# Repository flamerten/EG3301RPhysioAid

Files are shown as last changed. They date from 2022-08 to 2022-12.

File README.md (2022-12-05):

# Development of a Physiotherpay Aid
A project done by EIM322 with the National University of Singapore's Innovation and Design Programme([iDP](https://cde.nus.edu.sg/idp/academics/overview/)). Under the Innovating for a Better Healthcare Track, we propose the use of multiple knee wearables during group physiotherapy sessions, allowing physiotherapists to identify patients that are struggling and devote more time into correcting their form or modifying their individual exercises.

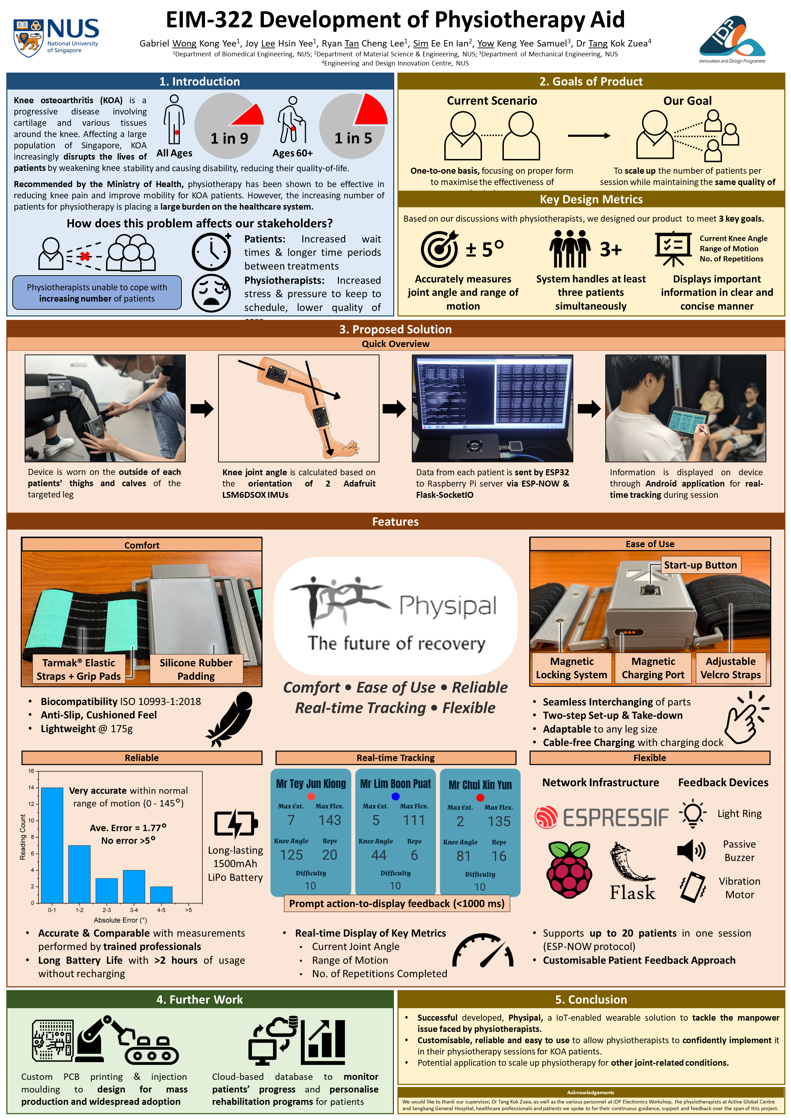
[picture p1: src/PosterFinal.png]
Poster


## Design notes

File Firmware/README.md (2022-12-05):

# Firmware

This is the set of files where we use the Adafruit components to reduce the size, the M5 was quite thick and didn't have some features that we wanted so we changed our electronic components.

# Hardware

## List of key components
- [ESP32 Feather V2](https://www.adafruit.com/product/5400)
- [LSM6DSOX 6 DoF Accelerometer and Gyroscope](https://www.adafruit.com/product/4438)
- [LC709203F LiPoly / LiIon Fuel Gauge and Battery Monitor](https://www.adafruit.com/product/4712)
- [Tactile Switch Buttons(12x12x6)](https://www.adafruit.com/product/1119)
- [Pogo Pin Connectors](https://shopee.sg/5-Pairs-Spring-Loaded-Magnetic-Pogo-Pin-Connector-3-Positions-Magnets-Pitch-2.3MM-Through-Holes-Male-Female-Probe-i.174316421.13592238478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)
- [Vibration Motor Module](https://shopee.sg/PWM-Vibration-Motor-Module-DC-Motor-Mobile-Phone-Vibration-Vibrator-Mini-Switch-Sensor-Module-DIY-for-Arduino-DC-5V-i.56539845.10481910192)
- [1500mah Lipo Battery](https://www.continental.sg/3-7v-rechargeable-1500mah-li-po-battery.html) - Continental Electronics, Sim Lim Square
- [5V Boost Converter](https://shopee.sg/5pcs-lot-0.9-5V-To-5V-DC-DC-Step-Up-Power-Module-Voltage-Boost-Converter-Board-1.5V-1.8V-2.5V-3V-3.3V-3.7V-4.2V-To-5V-i.56539845.12267989957)

## Adafruit
Note that we chose Adafruit because their components are of pretty solid quality and their STEMMA QT Cables are pretty useful for the i2c wiring. We also used that ESP32 feather because it came with battery charging capabilities. 

The pogo pin connectors were used for charging and for connecting the upper casing to the lowercasing. The lower casing houses the Vibration Motor as it needs to be close to the skin.

The tactile switch buttons we used are slightly bigger than the typical ones, and are generally alot easier to press. 

Note that the LiPo batteries must be bought locally, as they take very long to be shipped over. They also must be treated carefully and cannot be pierced by screws/sharp parts or overcharged. The Feather handles this well.

The Motor is connected to a Boost Converter to as it will increase the voltage across the motor and hence the magnitude of vibration

## Electrical Circuits

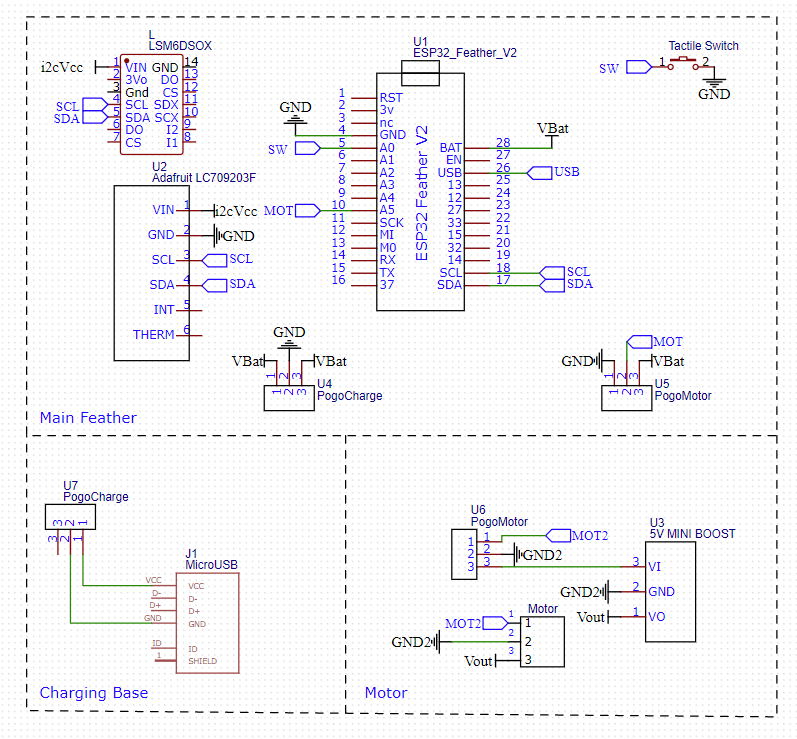
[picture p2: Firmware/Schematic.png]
Electrical Circuit


Note that the LIPO Battery should be connected to the LC709203F via JST, then the other JST cable from the LCF70920 will run to VBat in the Huzzah and the the Ground wire connects to GND.

# Software

The communication relied on [ESP-NOW](https://randomnerdtutorials.com/esp-now-esp32-arduino-ide/), with the MAC ADDRESSES specified in the codes. The Feather with the motor is denoted as the **Slave** while the one without is denoted as the  **Master**. The Slave calculated the orientation and transmits it to the Master. The Master then calculated the joint angle in this format, with maximum flexion being 0 degrees. This was advised by Mark from Active Global

    joint_angle = 180 - abs(180 - int(abs(slave_angle - roll)));

The Master then uses ESP-NOW to transmit data to the M5. The M5 then processes the joint angle from multiple Feathers and transmits it to the Raspberry Pi via Serial to be processed. When the Raspberry Pi senses that a patient has completed a repetition by hitting the max/min, it sends the patient number via Serial to the M5. The M5 then sends an ESP-NOW message to the Slave, which will vibrate the motor. 

The orientation is calculated via the AHRS algorithm provided by [MadgwickAHRS Library](https://github.com/arduino-libraries/MadgwickAHRS). As the Magdwick Algorithm relies on gradient descent, we found that the first few seconds of data were generally inaccurate as it was still descending to the actual position. As such, the first 10s of readings were ignored, and data only starts to be transmitted after that.

The Magdwick Algorithm calculated roll and pitch. However, we needed Yaw, as this was the optimal placement of the LSM in the wearable. As such, the frame was rotated and fed into the Magdwick Algorithm, such that the roll calculated is actually the Yaw.

    //filter.updateIMU(gx, gy, gz, ax, ay, az);  //Original
    filter.updateIMU(gz, gy, -1.0*gx, az, ay, -1.0*ax); //Yaw, rotated > used

I also noted that the readings were incredibly noisy when the LSM faced upwards, with its Z axis pointing up. I believe its because only one axis is used. Once it is tilted, it is able to utilise readings from multiple axis. Refer to (this)[https://community.nxp.com/t5/Sensors/6DOF-GY-KALMAN-Yaw-drift/m-p/457552] forum post i found.

## Notes
Note that PATIENT_NO = 0 is old prototype with the IMU rotated and holes in the board  Hence, the Battery indicator brightness is lower and the orientation calculation is different. These are accounted for in the code with if else statements

# Mac Addresses

M5
- {0x4C,0x75,0x25,0xC4,0xFA,0xF4}; 

Patient 1 (NEW) -> purely grey
- New Master: {0xE8,0x9F,0x6D,0x26,0x09,0x20}
- New Slave: {0xE8,0x9F,0x6D,0x1F,0xFD,0xB8}

Patient: 0 (OLD PROTO) -> Large prototypes
- Old Master: {0xE8,0x9F,0x6D,0x25,0x3C,0x24}
- Old Slave:  {0xE8,0x9F,0x6D,0x28,0x0C,0x98}

Patient 2 (Newest Feathers) - Turqoise Casing
- Master: {0xE8,0x9F,0x6D,0x25,0x47,0x08}
- Slave:{0xE8:0x9F,0x6D,0x25,0x46,0x70}

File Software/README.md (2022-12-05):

# Software

A Raspberry Pi running Flask SocketIO was used to set up the network for the wearable to communicate with the mobile phone. The mobile phone application for physiotherapists was developed using Android Studio.

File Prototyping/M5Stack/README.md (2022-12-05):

# M5Stack - Initial Prototyping

This folder contains the master and slave codes, for 2 slave M5s to connect to 1 M5. This M5 is connected to my computer and outputs the rolls of each M5 and the joint angle. The angle is calculated by this way, with rolls_rsv containing the rolls of the 2 IMUs.

    angle_knee = int(abs(rolls_rcv[0] - rolls_rcv[1]) );
    if(angle_knee > 180) angle_knee = 360 - angle_knee;

The communication relied on [ESP-NOW](https://randomnerdtutorials.com/esp-now-esp32-arduino-ide/). The roll is calculated by the AHRS algorithm provided by [M5 docs](https://docs.m5stack.com/en/api/atom/mpu).

When the slave M5s have turned on, they start a calibration sequence. As it is gradient descent, i give the condition that i need to do calibration for at least 3s, and that the difference between the max and min must be less that 1 degrees. This ensures that the reading has stablised. This offset is added to the future rolls added.

Once the calibration has been done, the slave M5s send a message every 1s via esp-now to the master device, in order to start the syncing. This allows the M5s to send the angles at the same period and similiar timings. Similar because if its exactly the same there might be some conflict when ESP-NOW sends its messages. So i add a small delay of 50ms.

This broadcast/callibration message consists of the slave MacAddress. It only starts sampling when it has recieved the order from the master M5 to start sampling. The reason for the MacAddress is that this allows the M5 master to differentiate M5s. Also, the message to start sampling is sent to both slave M5s, once 2 **different** esp now messages with different Mac addresses are recieved. The sending is sent to the slave M5s, with the message containing sampling rate and also a different roll angle to another device. 

From there both M5s sample the roll and send it via ESP-NOW to the master M5. The sampling rate is decided by the Master. 

The isssue is that the plan needs to be parallel to the z axis, meaning that the top of the M5 must point to the sky vertically.

#
## Updates
### 31/08/2022
Testing was generally good, the issue of calibration still not solved. However, the angles are relatively accurate when the devices are put on properly. An indicator is used to show which M5 recieves which message. I noticed there were some times where one M5 stop transmitting. The Master M5 indicator only showed one M5 sending, so not too sure why, will test and see the reason.

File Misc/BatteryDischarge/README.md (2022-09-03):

# Power Source

This folder details experiments and changes made to the power supply of the physiotherapist wearable.  This is neccessary to ensure physiotherapists charge the device to ensure it does not run out of charge, and to fully utilise the capacity of the battery.

## 03/09/22
#

## **Resistors**

The aim of the experiment was to see if using potential difference was a feasible way of estimating battery capacity. A multimeter was used to get the true value of the potential difference and that value is compared to the analogRead when resistors are applied in a potential divicer circuit. This is the circuit used:

    VCC - R1 * R1 - GND 
    
with * being where the analogRead is taken from. The reason for this is because our MCU is 3.3V logic level. As the battery has a maximum voltage level of 4.2V, this is to ensure the logic level is not exceeded.

From some preliminary experiements, there was quite abit of inaccuracy. Firstly, with higher resistances, the ADC within the MCU is more inaccurate as it works by storing charge. Hence, the low current decreases accuracy.

However at lower resistances, alot of voltage is lost to power loss due to the current at the branch. As such there was a consistent offset.

| Resistance  | Multimeter Voltage | Actual Volage |
| --- | --- | --- |
| 270 &Omega; | 2.59V | 2.74V | 
| 1 M&Omega;  | 2.45V | 2.08V - 2.74V |
| 100 K&Omega;| 2.58V | 2.40V |

As noticed the resistance did not seem to affect the offset heavily. However, a higher resistance had a very sigificant amount of fluctuation

## **Voltage Discharge**

A DC Motor Was used to discharge a fully charged LION battery and its potential difference was measured using 100K&Omega; resistors. The potential difference was sampled every 1s using the M5 Atom's ADC pin, and recorded on to a CSV file.

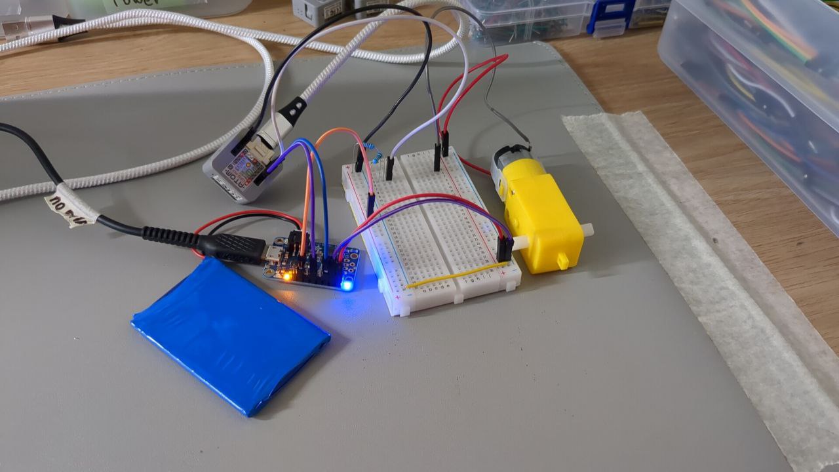
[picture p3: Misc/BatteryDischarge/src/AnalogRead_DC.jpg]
Electrical Setup


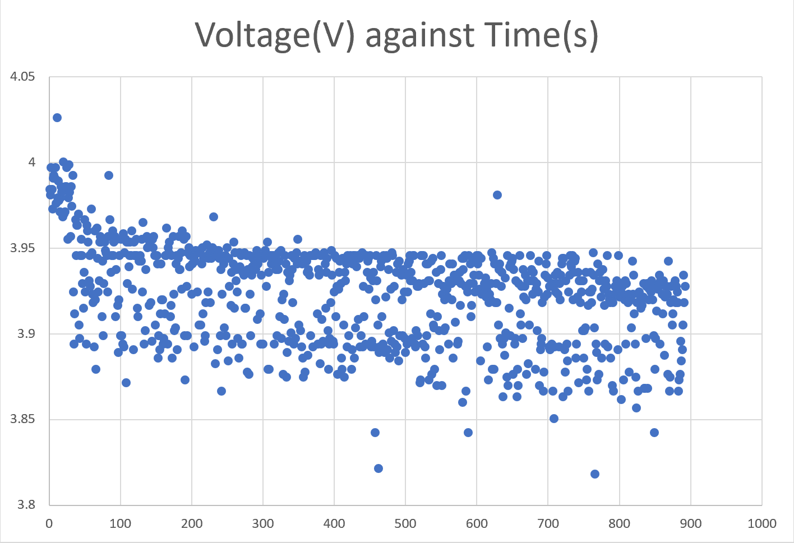
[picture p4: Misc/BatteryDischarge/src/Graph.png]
Voltage Graph Graph of Voltage Against Time


The voltage graph had alot of fluctuation. Although granted that this could be due to signal noise, but it might mean that we might need to implement some signal filtering techniques when using this method to estimate battery capacity. However, from this graph, it does not look like a very reliable method and we might need to consider using other methods to get the capacity of the battery.

Some possible Alternative Ways coule be using breakout boards that monitor the capacity of the battery.

## *Possible Links*

[Single Li-Ion and LiPoly Battery Power Meter](https://www.adafruit.com/product/5383)

[Adafruit LC709203F LiPoly / LiIon Fuel Gauge and Battery Monitor](https://www.adafruit.com/product/4712)

[Adafruit MAX17048 LiPoly / LiIon Fuel Gauge and Battery Monitor](https://www.adafruit.com/product/5580)

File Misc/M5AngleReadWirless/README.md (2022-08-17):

# M5AngleReadWireless

This folder contains the a master and slave code where a M5 Atom Matrix with the inbuilt MPU6886 to read the 6 axis IMU readings. These readings are processed through the AHRS algorithm provided by M5 docs and then sent via ESP-NOW to a master M5. The master M5 reads this data and prints them onto a serial monitor.

Note for use with another MCU, you need to change the mac address

The current mac address that recieves the angles is: {0x4C,0x75,0x25,0xC4,0xFA,0xF4}

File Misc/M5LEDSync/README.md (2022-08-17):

# M5 LED Sync

Initial testing code for syncing LEDS, using ESP-now

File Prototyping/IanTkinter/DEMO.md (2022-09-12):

# Demo Instructions

## Requirements
    matplotlib==3.5.2
    pyserial==3.5

This files details the steps for using the M5 IMUs with guibuild file, to show the joint angle in real time. This demo is the same as how we demoed with Mark at Active Global.

1) Using a type c cable, plug the Master M5 Atom into the USB port of a computer. Check that the cable is a data cable, by opening `Device Manager > Ports ` If you see the M5 atom there then you are good to go. Note that the Master M5 Atom has a grey wire on it, while the slaves do not have any wires at the GPIO ports

2) Attach 2 `Tailbat`s to the slave atoms. It should turn on immediately and show the green battery bar. If not press once. If there is no red light, the `Tailbat` has run out of battery, use another one. 

3) Note that there is no more callibration. After 2s, the master M5 should have 2 flashing RGB lights. This signifies that it is recieving data from the 2 slave atoms

4) Run the guibuild.py file. A Window should show the real time data of joint angle between the 2 M5 IMUs.

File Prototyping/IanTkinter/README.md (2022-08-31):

# Ian Tkinter

This folder shows Ian's work on using Tkinter to display data coming from the M5 with the connection through serial port

`ReadSerialData.py` is a python file that reads data coming from the serial port of the M5. It assumes that the data is coming in the format >  `angle angle angle`, with COM14 as the port. The data is read using pyserial and saved to a json file, `angle_json_data.json`

The JSON file is read continuously by the file `guibuild.py` it also uses Tkinter and Matplotlib to build a GUI to show patient knee angle (`angle_json_data`) and SEMG data (`emg_json_data.json`).

The arduino folder `RandomNumberGen` is used to generate random numbers for testing the use of Serial Data

#
## Updates

### 31/08/2022
Had some succeess in reading raw data, combining the data read from `M5AngleSync`. However, there was some issues in writing to the json file. This was solved with `try except`. The reason could be `guibuild.py` reads the json file at the exact same time that `ReadSerialData.py` writes to the file. Might need to reduce the frequency of updating the JSON file. 

Had some issues with speed as well, there are 6 graphs and each are updating at its own time. This can be pretty slow because its 6 seperate instances.

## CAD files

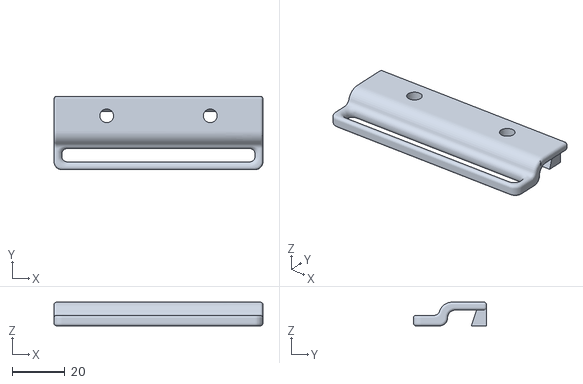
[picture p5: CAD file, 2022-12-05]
Mechanical/STL/Q.R 2.0 B v2.stl
79.3 x 27.8 x 9.00

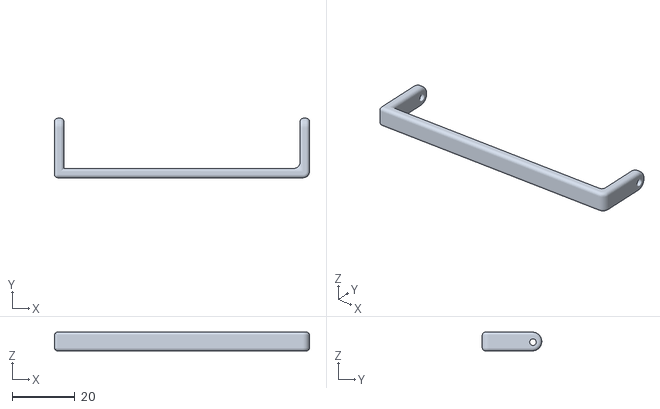
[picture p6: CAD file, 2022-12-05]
Mechanical/STL/Arm 2.0 v1.stl
81.3 x 19.0 x 6.00

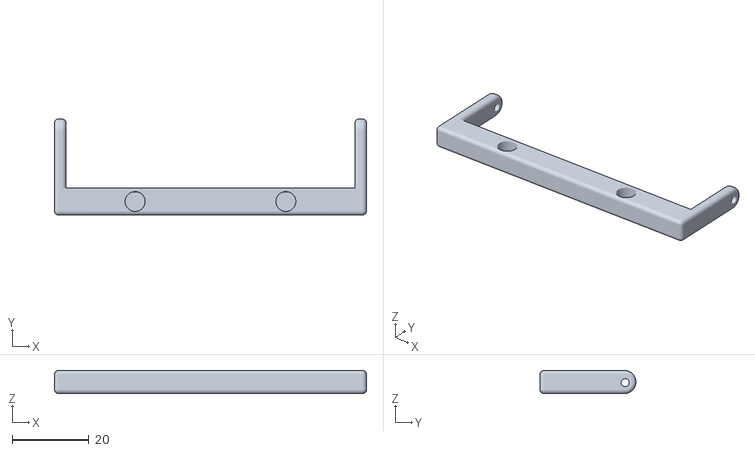
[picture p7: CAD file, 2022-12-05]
Mechanical/STL/Q.R 2.0 A v1.stl
81.3 x 25.0 x 6.00

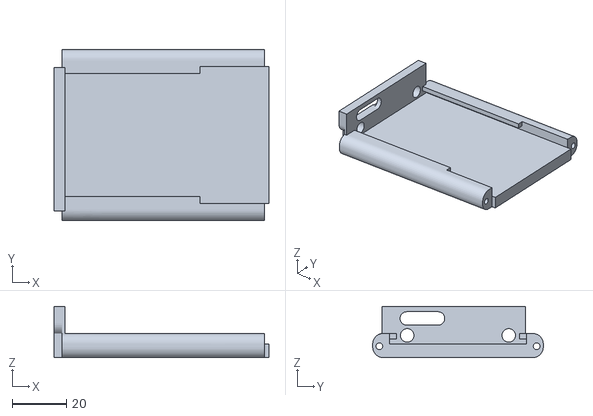
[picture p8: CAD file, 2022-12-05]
Mechanical/STL/Harness.stl
79.4 x 63.0 x 19.0

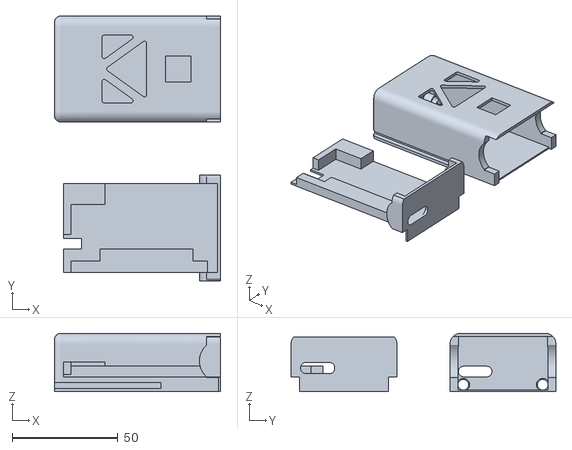
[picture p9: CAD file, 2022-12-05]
Mechanical/STL/Electrical housing.stl
78.4 x 125.0 x 27.5

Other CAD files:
Mechanical/Fusion File/Arm 2.0 v1.f3d
Mechanical/Fusion File/Electrical housing.f3d
Mechanical/Fusion File/Harness.f3d
Mechanical/Fusion File/Q.R 2.0 A.f3d
Mechanical/Fusion File/Q.R 2.0 B v2.f3d

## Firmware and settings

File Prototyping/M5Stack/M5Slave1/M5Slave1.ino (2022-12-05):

/*
Slave Sketch
This M5 recieves the esp-now message from the master and then  begins sampling
Sampling rate defined from the messgae recieved
*/

#include "M5Atom.h" //helper functions for the MPU
#include <Adafruit_NeoPixel.h> //This is for the onboard LEDs
#include <esp_now.h>
#include <WiFi.h>

const bool callibrate = false; //ignore callibration

//On board LED matrix
#define LED_COUNT 25
#define LED_PIN   27
#define BRIGHTNESS 50 //set as 0 if you do not want to show the indicator
bool led_off = true;
Adafruit_NeoPixel matrix(LED_COUNT,LED_PIN , NEO_GRB + NEO_KHZ800);

//CPU CLOCK
#define CLOCKSPEED 80
//function takes the following frequencies as valid values:
//  240(Def), 160, 80    <<< For all XTAL types
//  40, 20, 10      <<< For 40MHz XTAL

//Deep sleep button
#define BUTTON 39
#define BUTTON_PIN_BITMASK 0x8000000000 // 2^39 in hex
volatile bool go_to_sleep = false; //For the ISR

//BatteryAnalog
#define BATTERY 33
int BatLastChecked;
int BatNumber;
const int BatCheckInterval = 5*60*1000; //5mins

//ESP-NOW Communication
#define DEFAULT_DELAY_LAG 50 //communication delay
#define CALIBRATE_LAG 5000 //Let the IMU do gradient descent for N ms at least
uint8_t master[] = {0x4C,0x75,0x25,0xC4,0xFA,0xF4}; //GREY
bool data_rcv = false;
int sampling_period = 100; //Changed on data rcv > master sends the sampling period he wants
int delaylag;

//Use the same float for all 3 devices, Reduce complexity(?)
typedef struct struct_message{
    int sampling_rate;
    uint8_t slave_mac[6];
    float roll_angle;

} struct_message; //define struct and then initalise it

struct_message message;
esp_now_peer_info_t peerInfo;

//IMU
#define CALIBRATION_LAG 100
float pitch, roll, yaw;
float cal_roll, final_roll, final_roll_mapped;
unsigned long time_now = millis();
const uint8_t compare_no = 20; //compare n different readings during calibration
const uint8_t difference = 1; //1 degrees diff between readings = stabalise


void SetUpESPNOW(){
    WiFi.mode(WIFI_STA);

    // Init ESP-NOW
    if (esp_now_init() != ESP_OK) {
        Serial.println("Error initializing ESP-NOW");
        return;
    }

    esp_now_register_send_cb(OnDataSent);
    esp_now_register_recv_cb(OnDataRecv);

    peerInfo.channel = 0;
    peerInfo.encrypt = false;

    memcpy(peerInfo.peer_addr, master, 6);
    if (esp_now_add_peer(&peerInfo) != ESP_OK){
        Serial.println("Failed to add master");
        return;
    }    

}

void OnDataSent(const uint8_t *mac_addr, esp_now_send_status_t status) {

    //Mostly debugging messages > don't do anything

    //Serial.print("\r\nLast Packet Send Status:\t");
    //Serial.println(status == ESP_NOW_SEND_SUCCESS ? "Delivery Success" : "Delivery Fail");
    
    return;
}

void OnDataRecv(const uint8_t * mac, const uint8_t *incomingData, int len) {
    //Data is only recieved once to init sampling
    
    memcpy(&message, incomingData, sizeof(message)); //Save data to struct
    WiFi.macAddress(message.slave_mac); // reset message to be own mac address instead of the master one
    data_rcv = true; // Flag to start sampling
    sampling_period = message.sampling_rate;

}

void init_matrix(){
  //ensure the matrix behind is turned off, reduce power usage
  //however, this can be useeful as an indicator
  matrix.begin();
  matrix.clear();
  matrix.show();
  matrix.setBrightness(BRIGHTNESS);

}

void light_up(int r, int g, int b, int index){
  //12 is the centre of the matrix
  matrix.setPixelColor(index,matrix.Color(r,g,b));
  
}

bool arr_is_valid(float diff, float *arr ){
  //check if the diff between max and min is whithin the diff, for callibration 
  
  float max_value = -360.0;
  float min_value = 360.0;
  for(int i = 0; i < compare_no; i++){
    if(arr[i] > max_value) max_value = arr[i];
    if(arr[i] < min_value) min_value = arr[i];
  }

  return abs(max_value - min_value) <= diff;
}

void calibrate_IMU_MAX(){
  //It appears that this is gradient descent. 
  //As such i will wait for the readings to be stabalised by comparing the gradients
  
  Serial.println("Calibrating");
  
  float angle_storage[compare_no];

  int curr_index = 0;
  int count = 0;
  int time_now = millis();

  cal_roll = 0;

  while(1){
    CheckSleep();
    M5.IMU.getAhrsData(&pitch,&roll,&yaw);
    
    angle_storage[curr_index] = roll;

    if(arr_is_valid(difference, angle_storage) && (millis() - time_now > CALIBRATE_LAG) ){
      //check that the angle has stabalised
      //let the callibration time be that number to prevent early activation

      for(int i = 0; i  < compare_no; i++){
        cal_roll += angle_storage[i];
      }

      cal_roll = cal_roll / compare_no;

      Serial.println("Calibration Done");
      Serial.printf("Offset roll:%.2f", cal_roll);
      Serial.println();

      return;
    }
    else{
      if(curr_index >= compare_no - 1) curr_index = 0;
      else curr_index++;
      
      count++;
      if(count%20 == 0) Serial.println(count);
    }

    delay(CALIBRATION_LAG);
  }
  
}

void IRAM_ATTR SLEEP_ISR(){
  //GPIO interrupt that changes the variable go to sleep
  go_to_sleep = true;  
}

void Setup_DEEPSLEEP(){
  pinMode(BUTTON,INPUT_PULLUP);
  esp_sleep_enable_ext0_wakeup(GPIO_NUM_39,LOW); //Wake up when button pulled low
  attachInterrupt(BUTTON, SLEEP_ISR, FALLING); //Interrupt and go to sleep when button pulled low

}

int BatAmt(){
  
  return 2; //To show doctor linus
  
  int number = analogRead(BATTERY);
  int pd_out_map = map(number,0,4096,0,330); //Number reads from 0 to 4096 (12bit)
  float voltage = pd_out_map / 100.0 * 2.0;

  if(voltage > 3.9) return 3;
  else if(voltage > 3.0) return 2; //by right 3.2V for low battery but i suspect is not very accurate so i minus 0.2 form the actual value
  else return 1;

}

void DisplayBat(int number){
  matrix.clear();
  ShowBattery();

  switch(number){
    case 3: //green 3 bar
      light_up(0,100,0,11); light_up(0,100,0,12); light_up(0,100,0,13);
      break;
    case 2:
      light_up(0,100,0,11); light_up(0,100,0,12); light_up(0,0,0,13);
      break;
    case 1:
      light_up(100,0,0,11); light_up(0,0,0,12); light_up(0,0,0,13);
      break;
    case 0: //Clear the Middle, leave battery box
      light_up(0,0,0,11); light_up(0,0,0,12); light_up(0,0,0,13);
      break;
    case -1: //White during connection
      for(int i = 5; i < 20; i++){
        light_up(50,50,50,i);
      }
      break;
  }

  matrix.show();
}

void ClearMatrix(){
  matrix.clear();
  matrix.show();  
}

void ShowBattery(){
  for(int i = 5; i < 20; i++){
    light_up(50,50,50,i);
  }
}

void CheckSleep(){
  if(go_to_sleep){
    ClearMatrix(); //Turn off indicator and go to sleep
    Serial.println("Going to sleep");
    delay(1000);
    esp_deep_sleep_start();
  }  
}

void setup(){
  M5.begin();
  M5.IMU.Init();
  //setCpuFrequencyMhz(CLOCKSPEED);
  
  Serial.begin(115200);
  delay(100);
  
  go_to_sleep = false;
  pinMode(BATTERY,INPUT);

  init_matrix();
  BatNumber = BatAmt();
  BatLastChecked = millis();

  Setup_DEEPSLEEP();
  
  SetUpESPNOW();
  Serial.println("ESP-NOW setup");

  //Set Parameters not too sure why i can't do it before setup
  //uint8_t mac[6];
  WiFi.macAddress(message.slave_mac); // Copy the current mac address to mac 
  Serial.println(WiFi.macAddress()); 
  //memcpy(message.slave_mac,mac,6); //6 Values in the mac address so byte sioze of 6 
  go_to_sleep = false;

  DisplayBat(BatNumber);
  
  if(callibrate) calibrate_IMU_MAX();

  bool off = false;
  data_rcv = true;
  while(!data_rcv){
    CheckSleep();
    //Only start when message is recieved, send one pulse every second
    esp_now_send(master, (uint8_t *) &message, sizeof(message));
    if(off){
      DisplayBat(-1);
      off = !off;
    }
    else{
      ClearMatrix();
      off = !off;
    }
    delay(1000); 
    Serial.println("Pulse sent out");
  }

  Serial.println("Data Recieved");

  //Set message variables to slave_no AFTER message recieved
  if(message.roll_angle == 1) delaylag = 0;
  else delaylag = DEFAULT_DELAY_LAG;

  message.roll_angle = -1; //reset roll angle
  
  delay(delaylag); //at the start of the setup, give some lag time
  time_now = millis();


}

void loop(){
  //Serial.println(millis() - time_now);
  if(millis() - time_now >= sampling_period){
      
    //LED indicator
    if(led_off) DisplayBat(BatNumber);
    else DisplayBat(0);

    //IMU calc and send
    M5.IMU.getAhrsData(&pitch,&roll,&yaw);
    final_roll = roll - cal_roll;

    if(final_roll > 180 ) final_roll_mapped = (final_roll - 180.0) * -1.0; //go to -ve
    else if(final_roll < -180) final_roll_mapped = (final_roll + 180.0) * -1.0; //go to +ve
    else final_roll_mapped = final_roll;

    
    Serial.print("Roll: ");
    Serial.print(roll);
    Serial.print(" Call_roll: ");
    Serial.print(final_roll);
    Serial.print(" Final_cal_Roll: ");
    Serial.println(final_roll_mapped);
    

    message.roll_angle = roll;
    esp_now_send(master, (uint8_t *) &message, sizeof(message));
    
    //Reset variable
    time_now = millis();
    led_off = !led_off; 

  }

  if(millis() - BatLastChecked >= BatCheckInterval){
    BatNumber = BatAmt();
    BatLastChecked = millis(); //Reset interval
  }


  CheckSleep();
}

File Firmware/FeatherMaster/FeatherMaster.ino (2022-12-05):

/*
 * MasterFeather -> Transmits Data to the M5. Vibration is optional
 * 
 */

#include <MadgwickAHRS.h> //https://github.com/arduino-libraries/MadgwickAHRS
#include <Adafruit_LSM6DSOX.h>
#include <Adafruit_LC709203F.h> //Bat indicator
#include <Adafruit_NeoPixel.h>
#include <esp_now.h>
#include <WiFi.h>

unsigned long int time_start_prog;

//Feather
#define NEOPIXEL_I2C_POWER 2
#define LED_BUILTIN 13
bool led_on = true;

//Deep sleep
#define SLEEP_BUTTON 26 //A0
gpio_num_t SLEEP_GPIO = GPIO_NUM_26; //Can't use int, some special type?
volatile bool go_to_sleep = false; //For the ISR

//ESP-NOW
#define PATIENT_NO 2 //Distiguish between patient nos
uint8_t master[] = {0x4C,0x75,0x25,0xC4,0xFA,0xF4}; //Master M5 > calculate Joint angle and send it to the M5



bool data_ready = false; //Flag when data is recieved
float slave_angle;
float joint_angle = 180;


typedef struct struct_message{
    float angle;
    uint8_t patient_no;
    //The slave sends angle to master, master calculates joint angle and then 
    //Sends that to the master
    //Use mac address to distinguish different wearables // No need this
} struct_message; //define struct and then initalise it

struct_message message;
esp_now_peer_info_t peerInfo;

//LSM IMU
Adafruit_LSM6DSOX sox; //declare sox object
sensors_event_t accel, gyro, temp;
unsigned long int imu_read_time = millis();
float roll, pitch;
float ax, ay, az;
float gx, gy, gz;

//Magdwick 
Madgwick filter;
#define SAMPLE_FREQ 10
#define STABALISE_DELAY 10000
const float GRAVITY = 9.81;
//const float RAD_TO_DEG = 180/3.142; //Commented out i think its already defined 
const uint16_t IMU_TIME_DELAY_MILLIS = 1.0/SAMPLE_FREQ * 1000;

//Batt Measurement
Adafruit_LC709203F lc;
unsigned const int BAT_TIME_DELAY_MILLIS =  60 * 1000; //Query every min
const float CUT_OFF_VOLTAGE = 3.3; //Source: https://forums.adafruit.com/viewtopic.php?f=19&p=545995 
#define USE_CUTOFF 0 //Dont use the cut off voltage
unsigned long int last_bat_query_time = 0;
int bat_percentage; float bat_voltage;

//Battery Indicator
Adafruit_NeoPixel onboard_pixel(1, 0, NEO_GRB + NEO_KHZ800); //Use on board neopixel

uint8_t BRIGHTNESS;

void(* resetFunc) (void) = 0; //declare reset function @ address 0

void CheckBattery(bool check_now){
    //Check_now used to just do a bat check during startup, from then on its false, until query time
    //First -> Check voltage, if too low shut off battery
    //Second, if query time, change the colour of the pixel
    
    bat_voltage = lc.cellVoltage();

    if(bat_voltage <= CUT_OFF_VOLTAGE && USE_CUTOFF){
        Serial.print("LOW BAT VOLTAGE: ");
        Serial.println(bat_voltage);
        go_to_sleep = true;
        return;
    }
    

    if( ( (millis() - last_bat_query_time) >= BAT_TIME_DELAY_MILLIS) || check_now){
        
        bat_percentage = round(lc.cellPercent());
        if(bat_percentage == 100 && check_now) onboard_pixel.setPixelColor(0,onboard_pixel.Color(50,50,50));
        //White signify full charge, only signify full charge at the beginning to avoid
        //Confusion
        else if(bat_percentage > 75) onboard_pixel.setPixelColor(0,onboard_pixel.Color(0,100,0)); //Green
        else if(bat_percentage > 40)  onboard_pixel.setPixelColor(0,onboard_pixel.Color(100,100,0)); //Yellow
        else onboard_pixel.setPixelColor(0,onboard_pixel.Color(100,0,0)); //Red

        onboard_pixel.show();

        Serial.print("Bat Level is "); Serial.print(bat_percentage); Serial.println("%");

        last_bat_query_time = millis(); //reset flag
    }

}

void IRAM_ATTR SLEEP_ISR(){
  //GPIO interrupt that changes the variable go to sleep
  go_to_sleep = true;  
}

void Setup_DEEPSLEEP(){
  pinMode(SLEEP_BUTTON,INPUT_PULLUP);
  esp_sleep_enable_ext0_wakeup(SLEEP_GPIO,LOW); //Wake up when button pulled low
  attachInterrupt(SLEEP_BUTTON, SLEEP_ISR, FALLING); //Interrupt and go to sleep when button pulled low

}

void CheckSleep(){
    if(go_to_sleep){
        digitalWrite(NEOPIXEL_I2C_POWER,LOW); //Turn of i2c
        Serial.println("Going to sleep");
        delay(500);
        esp_deep_sleep_start();
    }
}

void SetUpESPNOW(){
    WiFi.mode(WIFI_STA);

    // Init ESP-NOW
    if (esp_now_init() != ESP_OK) {
        Serial.println("Error initializing ESP-NOW");
        return;
    }

    esp_now_register_send_cb(OnDataSent);
    esp_now_register_recv_cb(OnDataRecv);
    
    peerInfo.channel = 0;
    peerInfo.encrypt = false;

    memcpy(peerInfo.peer_addr, master, 6);
    if (esp_now_add_peer(&peerInfo) != ESP_OK){
        Serial.println("Failed to add master");
        return;
    }    

}

void OnDataSent(const uint8_t *mac_addr, esp_now_send_status_t status) {

    //Mostly debugging messages > don't do anything

    //Serial.print("\r\nLast Packet Send Status:\t");
    //Serial.println(status == ESP_NOW_SEND_SUCCESS ? "Delivery Success" : "Delivery Fail");
    
    return;
}

void OnDataRecv(const uint8_t * mac, const uint8_t *incomingData, int len) {
    memcpy(&message, incomingData, sizeof(message)); //Save data to struct

    slave_angle = message.angle;
    data_ready = true; //flag to send updated data to the M5
}

void CheckToSend(){
  //Send to M5
  if(data_ready && ( (millis() - time_start_prog) >= STABALISE_DELAY)){
    //Use roll
    joint_angle = 180 - abs(180 - int(abs(slave_angle - roll)));
    //Set max flex of healthy person to be 0

    message.angle = joint_angle;
    esp_now_send(master, (uint8_t *) &message, sizeof(message));
    data_ready = false;

    //Debug
    Serial.printf("Slave:%i Master:%i Joint:%i", slave_angle, roll, joint_angle);
    Serial.println();

  }
}

void get_readings(){
  //Get readings from LSM, convert them to parameters and update IMU with it
  sox.getEvent(&accel, &gyro, &temp);

  //Accel in m/s^2 > convert to g
  ax = accel.acceleration.x/GRAVITY;
  ay = accel.acceleration.y/GRAVITY;
  az = accel.acceleration.z/GRAVITY;

  //Gyro in rad/s > convert to deg/s
  gx = gyro.gyro.x * RAD_TO_DEG;
  gy = gyro.gyro.y * RAD_TO_DEG;
  gz = gyro.gyro.z * RAD_TO_DEG;
  
  //filter.updateIMU(gx, gy, gz, ax, ay, az);  //Original

  //Rotate Matrix
  if(PATIENT_NO == 0) filter.updateIMU(gy, gx, gz, ay, ax, -1.0 * az); // Side
  else filter.updateIMU(gz, gy, -1.0*gx, az, ay, -1.0*ax); //Yaw // Found to be quite noisy when facing directly upwards
  
}
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

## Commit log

2022-08-08 Calibration, Matrix LED inited
2022-08-09 Update Calibartion Seq
    Decided to compare the max and min and ensure the variation was only 1 degrees. The calibration takes some time due to the nature of the gradient descent, tested out the range of roll and pitch
2022-08-09 M5 Cal Created
    Calibration through one point, and modifying the accelerometer and gyroscope values
2022-08-29 Fix Bugs
    Serial Read > Fixed compile error
    Slave > Battery indicator, Deep sleep and decrease clock speed to save power
    [M5SerialRead.ino, M5Slave1.ino]
2022-09-03 Battery Discharge Experiement And results updated
    [Data.csv]
2022-09-04 M5 update for demo
    -Improved angle to be more reliable
    -set battery to default 2 bar
2022-09-09 Demo changes
    Remove calibration, as we are taking relative angle, its faster
2022-10-01 Simple Angle Communication
    -Multiple Slaves to Master M5 which is connected via USB
    -Hardcoding MacAddress with PatientNumber being a message sent
    -Implemented Vibration from a set angle(60) for Patient 2, Master 2
    [Master1.ino, Master2.ino, MasterM5.ino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]
2022-12-05 Clean up
    [Arm 2.0 v1.f3d, Arm 2.0 v1.stl, Data.csv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]
